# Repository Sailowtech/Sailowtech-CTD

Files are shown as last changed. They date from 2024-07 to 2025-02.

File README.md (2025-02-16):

# Sailowtech-CTD - Low-Tech CTD Probe
Welcome on the repository of the Sailowtech CTD Project, an affordable and open-source CTD probe tailored for scientific expeditions.

## Why does this project exist?
After all, Open Source CTD probes already exist? Indeed, there are some great projects like [Open CTD](https://github.com/OceanographyforEveryone/OpenCTD "Open CTD Project") or [CTDizzle](https://github.com/IanTBlack/CTDizzle/tree/main "CTDizzle Project"), but we wanted something more tailored for mid to long term expeditions while allowing a modularity in the embedded sensors. Therefore, we aim to develop a project around a main electronic core and auxiliary cards that can be swapped depending on the research interest. For the moment, we propose a core based on a Raspberry PI Zero 2 W and an auxiliary cards for 2 Atlas Scientific Sensors (Conductivity, Temperature, Dissolved Oxygen, pH...).

## Issues
If you encounter any issues, please use the Issue tracker on GitHub. Please note that this project is still in the development phase and currently undergoing testing.

## Full documentation
The full documentation is accessible under [https://sailowtech.github.io/Sailowtech-CTD/](https://sailowtech.github.io/Sailowtech-CTD/)

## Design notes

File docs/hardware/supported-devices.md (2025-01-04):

# Supported Devices

This page lists all supported sensor devices.

## Bluerobotics Bar30 - High-Resolution 300m Depth/Pressure Sensor

Default I2C-Address: 0x76

Sailowtech-ID: *BAR30_DEPTH*

Vendor Page: https://bluerobotics.com/store/sensors-cameras/sensors/bar30-sensor-r1/

Provides Metric: Pressure / Depth

## Atlas Scientific Conductivity Probe with EZO circuit

Default I2C-Address: 0x64

Sailowtech-ID: *ATLAS_EZO_CONDUCTIVITY*

Vendor Page:
- https://atlas-scientific.com/embedded-solutions/ezo-conductivity-circuit/
- https://atlas-scientific.com/probes/mini-e-c-probe-k-1-0/

Provides Metric: Conductivity

## Atlas Scientific Dissolved Oxygen with EZO circuit

Default I2C-Address: 0x61

Sailowtech-ID: *ATLAS_EZO_DO*

Vendor Page:
- https://atlas-scientific.com/embedded-solutions/ezo-dissolved-oxygen-circuit/
- https://atlas-scientific.com/probes/industrial-dissolved-oxygen-probe/

Provides Metric: Dissolved Oxygen

## Atlas Scientific Temperature Sensor
PT-1000 or PT-100, can be in Dissolved Oxygen Probe

Default I2C-Address: 0x66

Sailowtech-ID: *ATLAS_EZO_TEMP*

Vendor Page:
- https://atlas-scientific.com/embedded-solutions/ezo-rtd-temperature-circuit/
- https://atlas-scientific.com/probes/industrial-dissolved-oxygen-probe/

Provides Metric: Temperature

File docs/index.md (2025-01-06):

# Sailowtech-CTD

Welcome to the Documentation of the Sailowtech-CTD project!
This project is run by [Sailowtech](https://sailowtech.ch), an association at [EPFL](https://epfl.ch).

The repository of the project is located at [https://github.com/Sailowtech/Sailowtech-CTD](https://github.com/Sailowtech/Sailowtech-CTD). Please use the issue tracker over there if you want to report any issues.

## Setup Raspberry PI
To set up the Raspberry Pi on a CTD, the image needs to be flashed. Details are on this page: [Installation and Setup](operating-system/installing.md)

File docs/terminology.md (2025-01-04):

# Terminology

This page outlines the basic terminology used in this project.

## Metric

A **metric** is a type of measurement.
For example, *Temperature*, *Pressure* and other such things.

## Measurement

A **measurement** is a datapoint with the value of a *metric* which was measured at a specific time.

## Sensor

A **sensor** is a physical device which is installed on the CTD. It takes measurements of a metric. Note that even though some devices take measures of multiple metrics, we abstract it to one metric per device. 

## Correlation Data

**Correlation Data** can be used to add additional measurements to the recorded data. This is mostly the case to add location and speed data, since the CTD is not tracking the location.

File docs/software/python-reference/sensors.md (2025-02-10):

# Sensors
## Generic Sensor

::: sailowtech_ctd.sensors.generic

## Mock Sensor

::: sailowtech_ctd.sensors.mocksensor

## Atlas Sensor

::: sailowtech_ctd.sensors.atlas

## Bluerobotics Sensor

::: sailowtech_ctd.sensors.bluerobotics

## Types

::: sailowtech_ctd.sensors.types

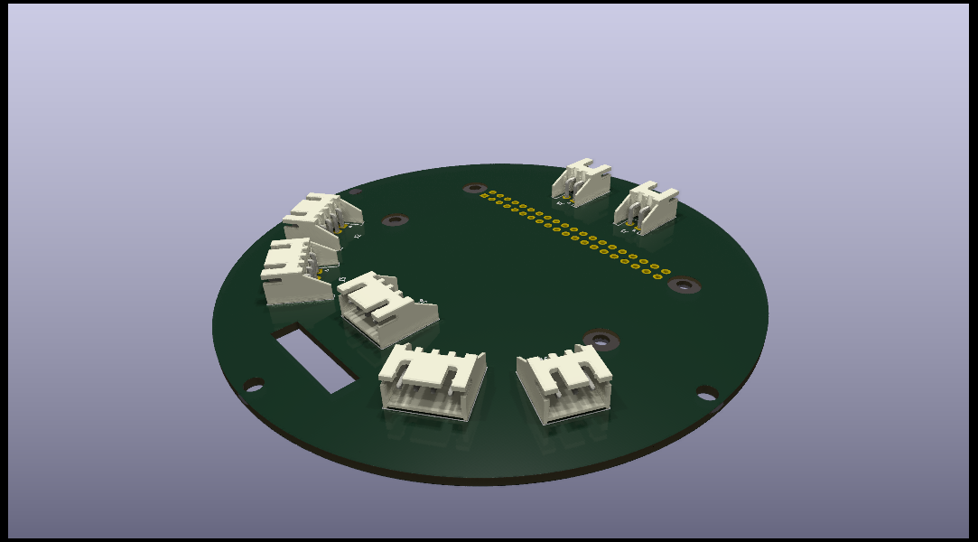
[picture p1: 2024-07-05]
hardware/ctd-base/ctd-base.png

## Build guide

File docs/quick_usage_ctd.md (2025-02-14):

# Quick usage guide

## Turn on the CTD
The CTD can be turned on by closing (turning clockwise) the on/off switch as marked in the image below.
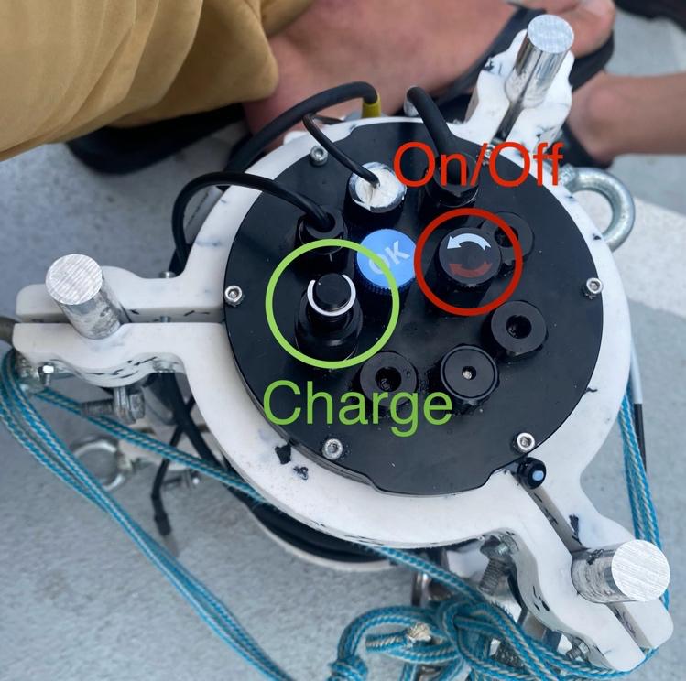
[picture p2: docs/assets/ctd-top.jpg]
CTD


## Connect to the CTD
The CTD will start after turning on the power supply. Please note that this might take up to one minute.
A Wi-Fi network called `CTD` will then appear. Connect to it with the password `CTDCTDCTD`.

!!! info "Development Build Access point"
    Please note that the Access Point name for the development build is called `CTDDEV`, but has the same password `CTDCTDCTD`

For further settings and system upgrades, it is possible to connect over SSH `ssh ctd@192.168.42.1` and password `ctd`.

## Record data using the web interface
If you are connected to the `CTD` Wi-Fi, the web interface is reachable over [http://192.168.42.1](http://192.168.42.1)

!!! warning "Web interface is currently being developed"
    The web interface is currently being developed. Some functionality is missing, and there are still some bugs.
    Mainly, there is no auto-reload, so please reload the web-page after starting a measurement and before stopping a measurement on the development web interface.

### Start a recording
To start a recording, click the button `Start Manual Run` on the webinterface. Only click it once. To make sure the recording has started, reload the page.

### Stop a recording
To stop the recording, click on the button `Stop Running` of the corresponding run in the webinterface.

### Download data
To download the data, locate the desired run in the list, and click on `Download data`

## Take a measurement with the CTD
!!! danger "Don't lose the CTD lol"
    Always make sure that the rope of the CTD is attached correctly, and the pressure closure (the round screw thingy on top with OK written on it) is fully screwed close.
    Note down the GPS coordinates, the depth and the water current direction in the unlikely case it gets lost.

To take a measure:

1. Attach the rope, check if the CTD is closed correctly, and remove the caps of the sensors
2. Make sure the boat is stopped and not moving too much
3. Note down the current GPS location and time
4. Connect to the CTD webinterface, start a manual run (as noted above), reload the webpage and write down the run-id - this is the number indicated at the beginning of the `Currently running` entry.
5. Put the CTD into the water, firmly attach the end of the rope to the boat
6. (When using for the first time, you might want to leave it in the water for ~3 minutes at 20cm depth, then take it out again, and check if no water got inside)
7. Lower the CTD into the water at a constant speed - for example 5cm/s -> 10 minutes to lower 30m
8. Leave the CTD at the lowest point for ~1 minute for the readings to stabilise
9. Pull the CTD up again. You can pull it up faster than the speed for lowering it. It also doesn't have to be constant.
10. Take the CTD out of the water
11. Connect to the Wi-Fi and webinterface again and stop the recording
12. Download the data of the run by clicking on the corresponding button

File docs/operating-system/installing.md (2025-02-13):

# Installation and Setup

It is assumed that a working CTD with a **Raspberry Pi Zero 2 W** is used for this setup.

## Download Image
The OS-images are automatically built for each release. Download the image (the file starting with *image*) of the latest release on the [Release Page](https://github.com/Sailowtech/Sailowtech-CTD/releases/).

Then, unpack the zip-file that was downloaded.

## Flash the image
The image needs to be flashed onto the SD-Card of the Raspberry Pi.
You can use one of those tools, for example:

- RPI-Imager: [https://www.raspberrypi.com/software/](https://www.raspberrypi.com/software/)
- Balena Etcher: [https://etcher.balena.io/](https://etcher.balena.io/)
- DD: [https://wiki.archlinux.org/title/Dd](https://wiki.archlinux.org/title/Dd)

Flash the downloaded *.img* file to the SD-Card by following the instructions of the tool you chose.

## Start the CTD, connect to the access point and log in
Plug in the SD-Card into the Raspberry Pi and start it. It will boot automatically and start an access point with the SSID `CTD`
Connect to this access point with password `CTDCTDCTD`. 

Then, connect over SSH with user `ctd` and password `ctd`:

`ssh ctd@192.168.42.1`

## Change passwords
Ideally, you should change the credentials of the `ctd`-user and also use another password for the access point.

The AP-password used can be changed in `/etc/hostapd/hostapd.conf`

## Setup internet access (if needed)
In case internet access is needed from the Raspberry Pi, you can set it up (with linux device as the other device, we'll call client).

1. Check which ip-address is assigned by the Raspberry Pi to the AP-client with `ifconfig` (for example: 192.168.42.4)
2. Enable IPv4-forwarding on client: `echo 1 | sudo tee /proc/sys/net/ipv4/ip_forward`
3. Set up iptables, replace `eth0` with name of interface with internet access and `wlan0` with name of interface connected to the Raspberry Pi:
   1. `sudo iptables -t nat -A POSTROUTING -o eth0 -j MASQUERADE`
   2. `sudo iptables -A FORWARD -i wlan0 -o eth0 -j ACCEPT`
4. Then, on the Raspberry Pi, add the route: `sudo ip route add default via 192.168.42.4` (adapt IP-address if required)
5. Add nameserver: `echo "nameserver 9.9.9.9" | sudo tee /etc/resolv.conf`

## Running the software

1. Connect to the Raspberry Pi
2. Change to the correct directory: `cd Sailowtech-CTD`
3. Start the webserver: `poetry run web`

It will then be reachable over: http://192.168.42.1:8000

Start measurements over http://192.168.42.1:8000/run?measurements=100 where the last number is the amount of measurements

Then http://192.168.42.1:8000/csv to get all the data

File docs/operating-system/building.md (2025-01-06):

# Self-Building Image

The image is built automatically on GitHub.

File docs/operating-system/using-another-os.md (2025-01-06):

# Use another Operating System

Of course, it is possible to use another Operating System instead of the one from the Sailowtech-CTD.

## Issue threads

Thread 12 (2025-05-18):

Time synchronisation not working correctly

maurosbicego, 2025-05-18:
The time synchronization in the web interface is not working correctly on the current development CTD device, even though tests were successful on a Raspberry Pi of the same model. Check if the cause lies in the general implementation or in the installation on the development CTD.

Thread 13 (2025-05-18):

Rework CSV export options

maurosbicego, 2025-05-18:
CSV export should / can now be possible with the different sensors distributed horizontally. One CSV entry per timestamp with the different values of the sensors. Now we have one CSV entry per sensor and timestamp.
Check implementation when downloading files in the web interface.

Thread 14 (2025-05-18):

Graph visualization is not working properly with an adapted config (Temperature data not available)

maurosbicego, 2025-05-18:
After adapting the config to a new set of sensors, the visualization in the web interface was not working properly. Data for temperature was not visible in our tests.

Example of missing temperature data:
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

(The data was measured correctly and is stored in the DB)

Used Config:

```
device: Sailowtech CTD
sensors:
  dissolved-oxygen:
    name: "Dissolved Oxygen 1"
    address: 0x61
    sensor-type: "ATLAS_EZO_DO"
    min-delay: 1.05
  dissolved-oxygen-2:
    name: "Dissolved Oxygen 2"
    address: 0x62
    sensor-type: "ATLAS_EZO_DO"
    min-delay: 1.05
  conductivity:
    name: "Conductivity Probe"
    address: 0x64
    sensor-type: "ATLAS_EZO_CONDUCTIVITY"
    min-delay: 1.05
  temperature-do:
    name: "Temperature (DO Sensor)"
    address: 0x67
    sensor-type: "ATLAS_EZO_TEMP"
    min-delay: 1.05
  depth:
    name: "Depth Sensor"
    address: 0x76
    sensor-type: "BLUEROBOTICS_BAR30_DEPTH"
    min-delay: 1.05
mock: false
```

Reporter: @benedictelunven

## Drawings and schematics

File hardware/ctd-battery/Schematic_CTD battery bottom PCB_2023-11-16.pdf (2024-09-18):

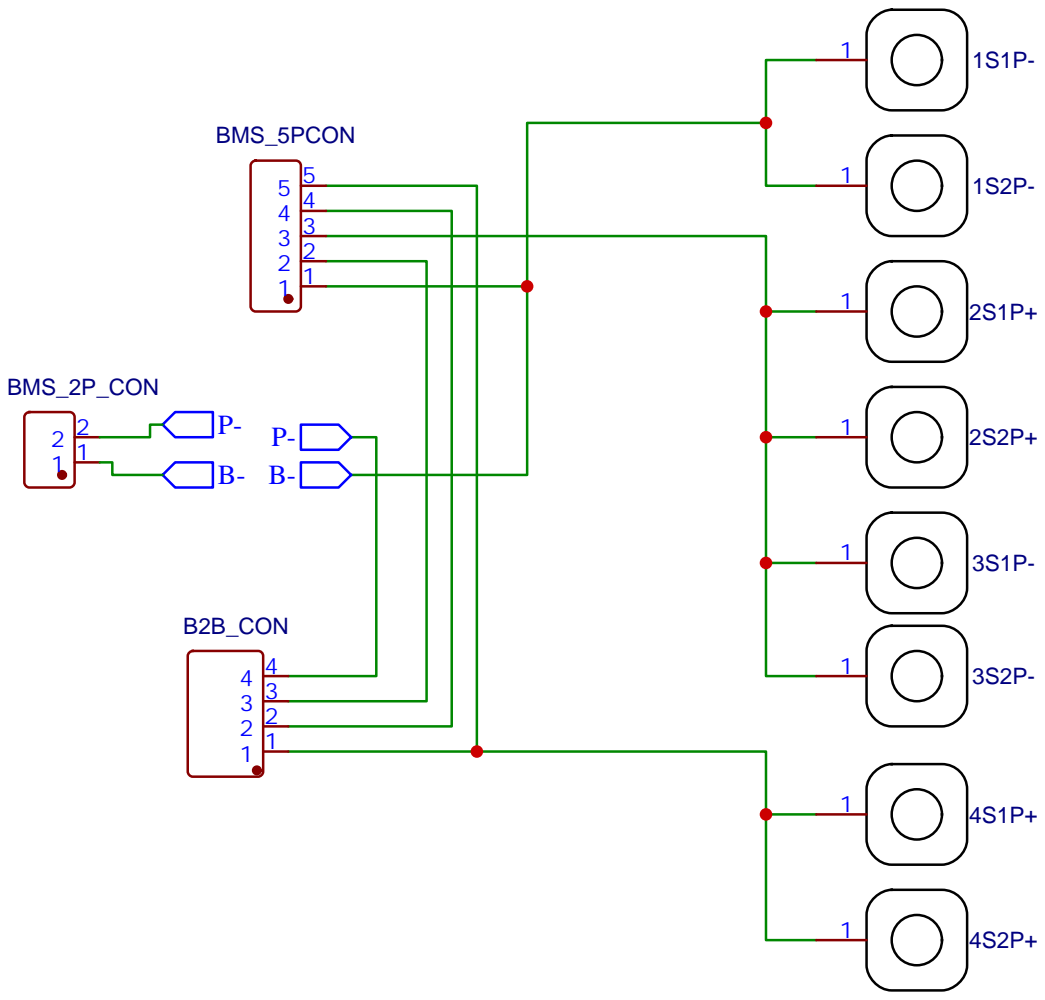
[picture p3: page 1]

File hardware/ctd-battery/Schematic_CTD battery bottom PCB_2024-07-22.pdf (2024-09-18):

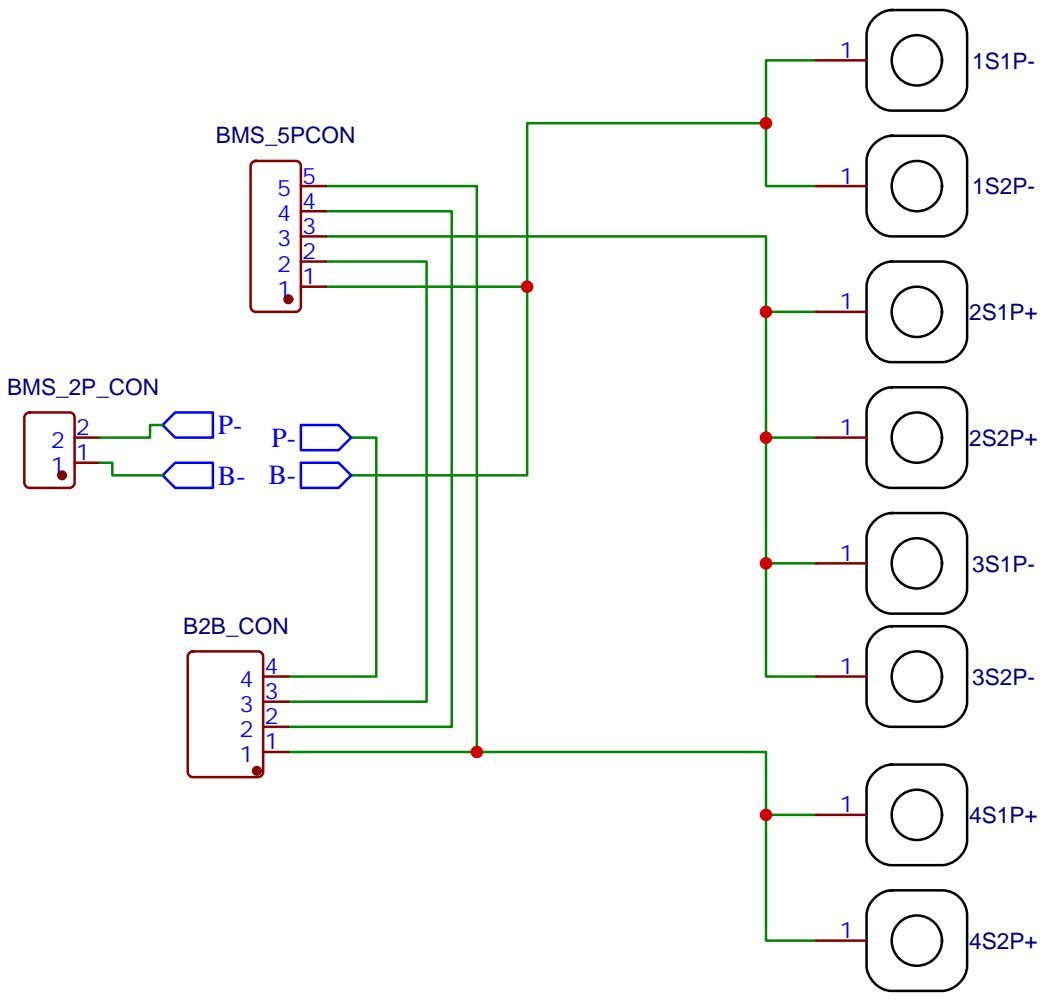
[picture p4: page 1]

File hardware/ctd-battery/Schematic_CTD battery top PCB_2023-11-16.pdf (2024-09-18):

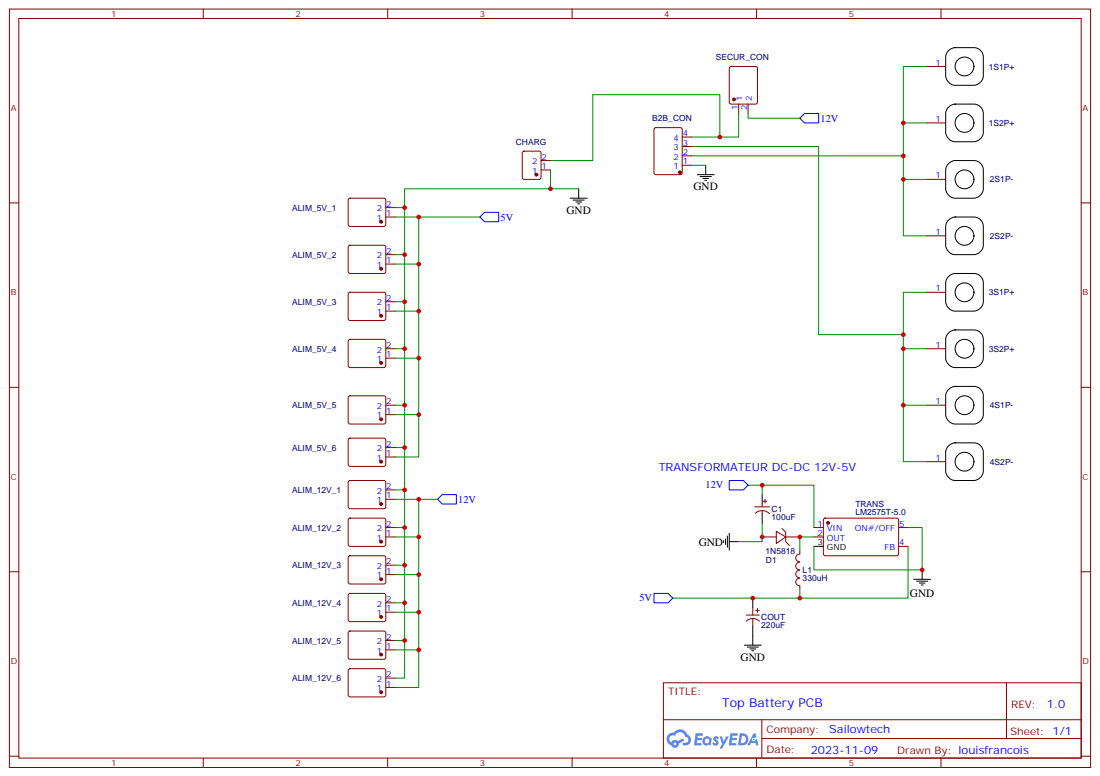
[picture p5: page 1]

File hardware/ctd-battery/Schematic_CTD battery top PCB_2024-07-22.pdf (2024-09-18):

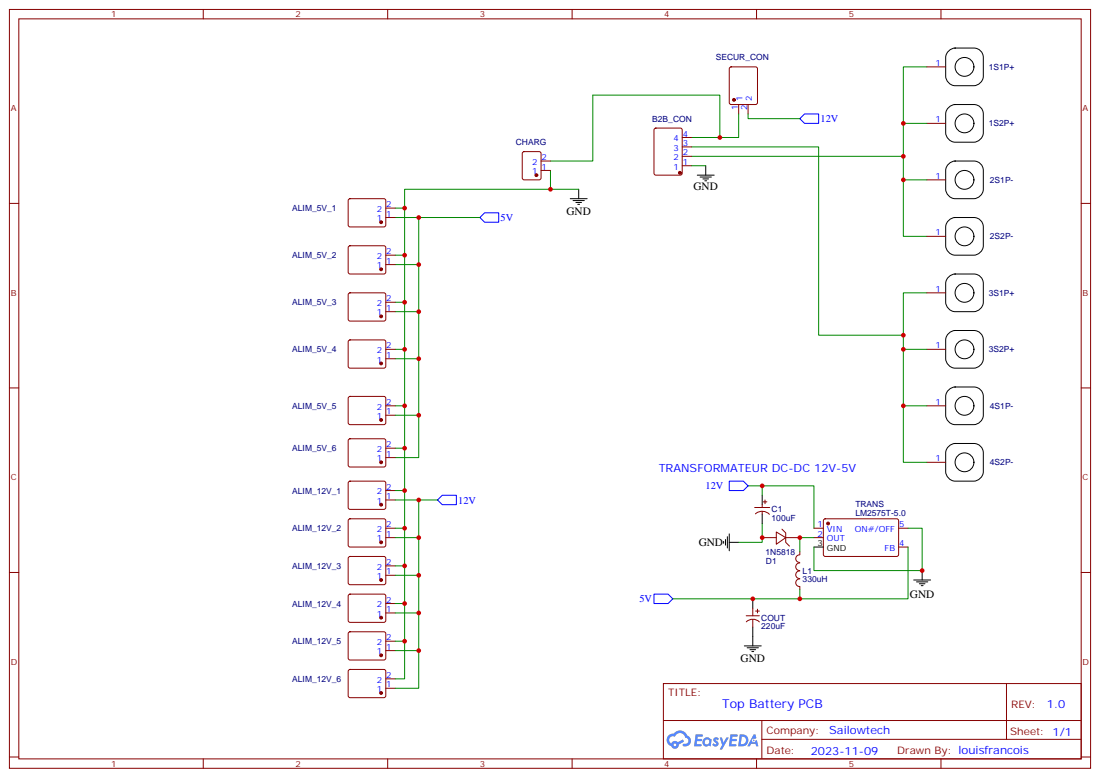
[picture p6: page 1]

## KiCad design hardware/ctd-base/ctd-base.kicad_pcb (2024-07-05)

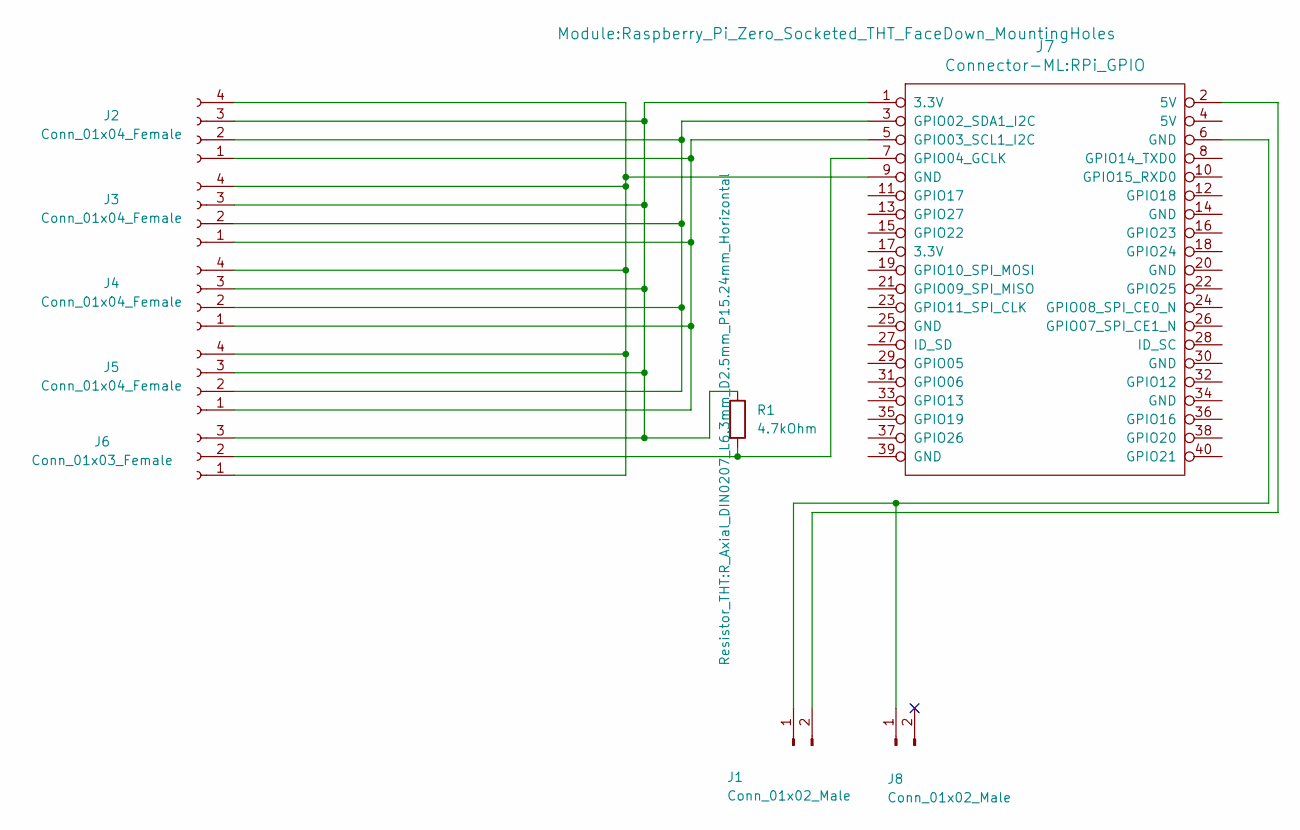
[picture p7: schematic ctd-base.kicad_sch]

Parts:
J1, J8: Conn_01x02_Male; JST_XH_S2B-XH-A_1x02_P2.50mm_Horizontal
J2, J3, J4, J5: Conn_01x04_Female; JST_XH_S4B-XH-A-1_1x04_P2.50mm_Horizontal
J6: Conn_01x03_Female; JST_XH_S3B-XH-A_1x03_P2.50mm_Horizontal
J7: Connector-ML:RPi_GPIO; Raspberry_Pi_Zero_Socketed_THT_FaceDown_MountingHoles
R1: 4.7kOhm; R_Axial_DIN0207_L6.3mm_D2.5mm_P15.24mm_Horizontal

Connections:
unnamed: J1.1, J7.6 (GND), J8.1
unnamed: J1.2, J7.2 (5V)
unnamed: J2.1, J3.1, J4.1, J5.1, J7.5 (GPIO03_SCL1_I2C)
unnamed: J2.2, J3.2, J4.2, J5.2, J7.3 (GPIO02_SDA1_I2C)
unnamed: J2.3, J3.3, J4.3, J5.3, J6.3, J7.1 (3.3V), R1.1
unnamed: J2.4, J3.4, J4.4, J5.4, J6.1, J7.9 (GND)
unnamed: J6.2, J7.7 (GPIO04_GCLK), R1.2

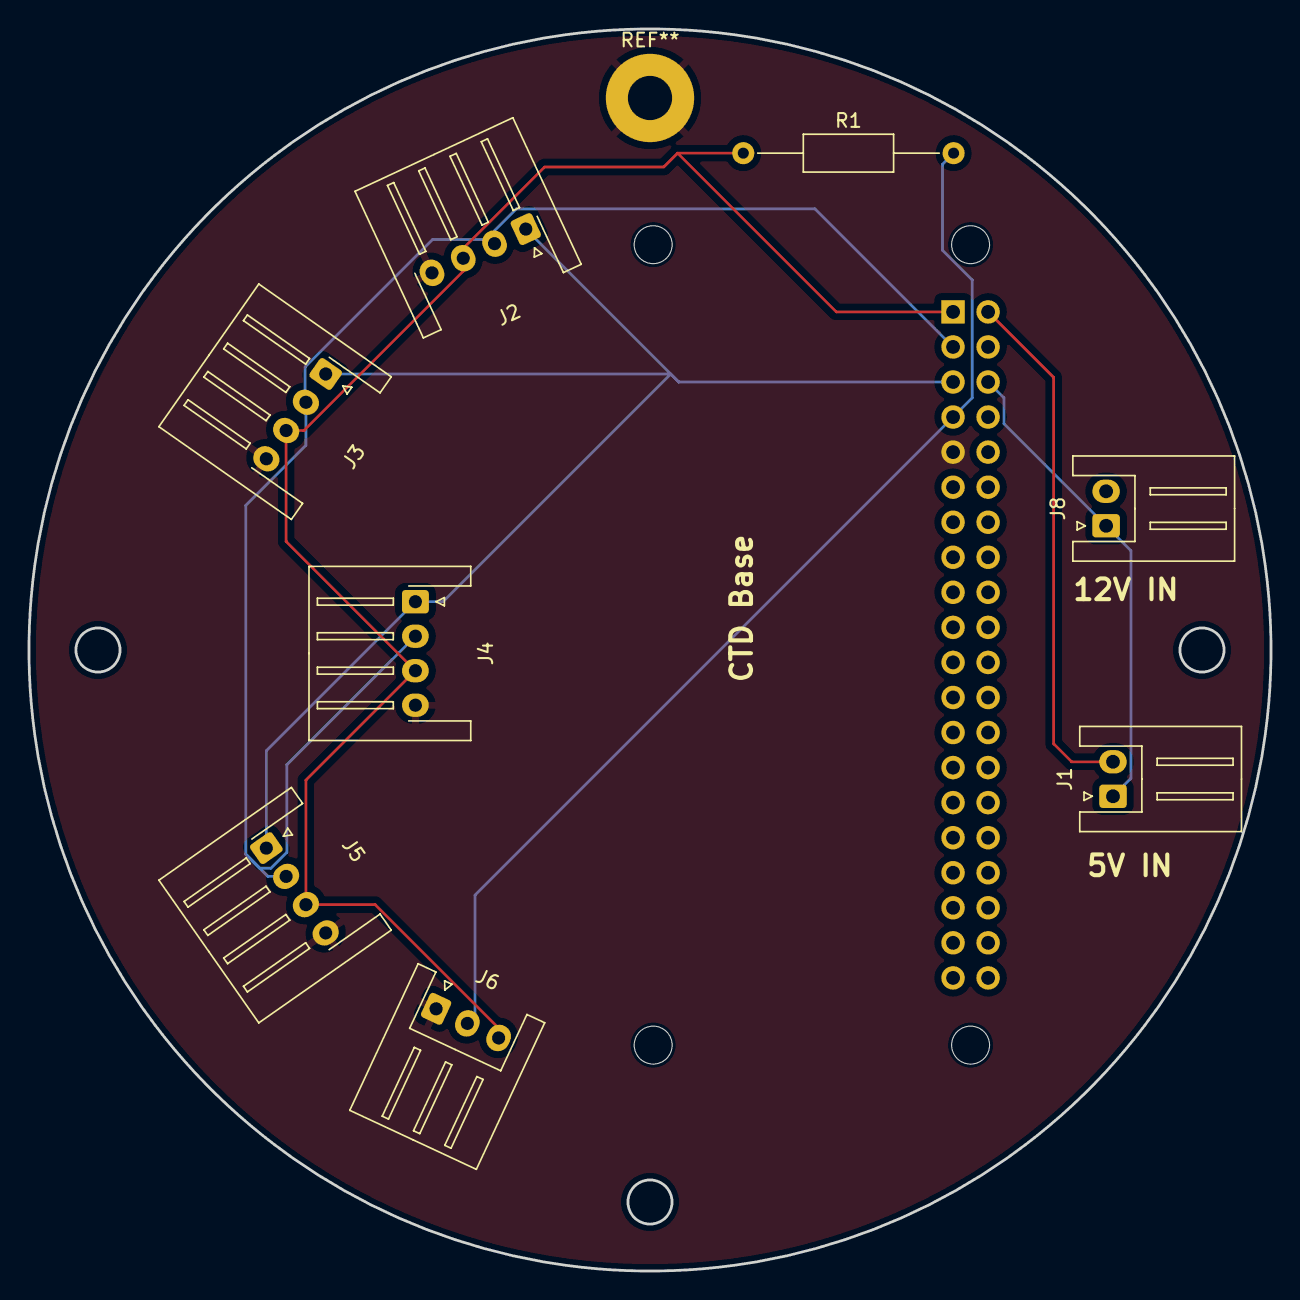
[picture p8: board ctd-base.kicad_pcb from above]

Board: 2 copper layers, 90.0 x 90.0 mm, 9 parts (1 on the bottom side), 7 nets.

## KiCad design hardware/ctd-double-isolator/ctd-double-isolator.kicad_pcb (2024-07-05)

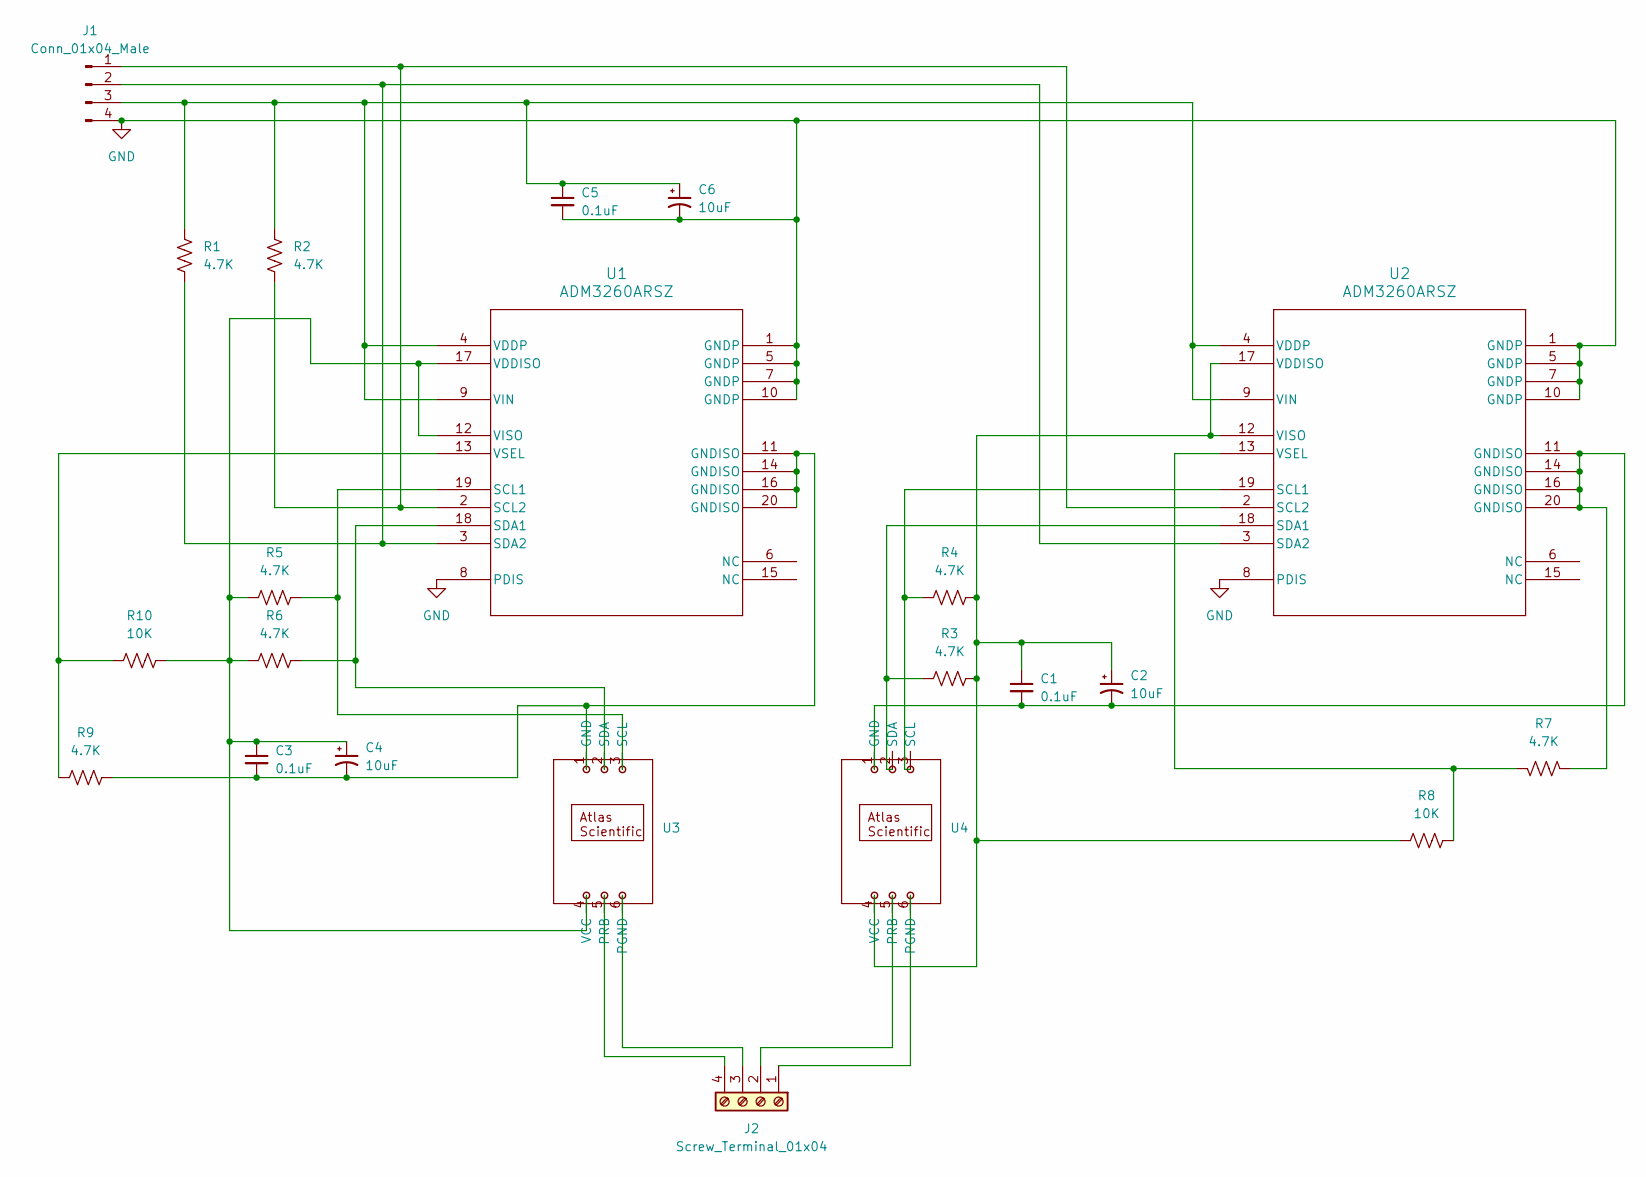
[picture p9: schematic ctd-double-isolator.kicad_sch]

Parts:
C1, C3, C5: 0.1uF; C_1812_4532Metric_Pad1.57x3.40mm_HandSolder
C2, C4, C6: 10uF; C_1812_4532Metric_Pad1.57x3.40mm_HandSolder
J1: Conn_01x04_Male; JST_XH_S4B-XH-A-1_1x04_P2.50mm_Horizontal
J2: Screw_Terminal_01x04; TerminalBlock_Phoenix_MPT-0,5-4-2.54_1x04_P2.54mm_Horizontal
R1, R2, R3, R4, R5, R6, R7, R9: 4.7K; R_Axial_DIN0207_L6.3mm_D2.5mm_P10.16mm_Horizontal
R8, R10: 10K; R_Axial_DIN0207_L6.3mm_D2.5mm_P10.16mm_Horizontal
U1, U2: ADM3260ARSZ; RS_20_ADI
U3: Atlas Scientific Dissolved Oxygen
U4: Atlas Scientific RTD Temperature Circuit

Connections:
GND: C5.2, C6.2, J1.4, U1.1 (GNDP), U1.5 (GNDP), U1.7 (GNDP), U1.8 (PDIS), U1.10 (GNDP), U2.1 (GNDP), U2.5 (GNDP), U2.7 (GNDP), U2.8 (PDIS), U2.10 (GNDP)
unnamed: J1.1, R2.2, U1.2 (SCL2), U2.2 (SCL2)
unnamed: J1.2, R1.2, U1.3 (SDA2), U2.3 (SDA2)
unnamed: C5.1, C6.1, J1.3, R1.1, R2.1, U1.4 (VDDP), U1.9 (VIN), U2.4 (VDDP), U2.9 (VIN)
unnamed: J2.1, U4.6 (PGND)
unnamed: J2.2, U4.5 (PRB)
unnamed: J2.3, U3.6 (PGND)
unnamed: J2.4, U3.5 (PRB)
unnamed: R5.2, U1.19 (SCL1), U3.3 (SCL)
unnamed: R6.2, U1.18 (SDA1), U3.2 (SDA)
unnamed: C3.1, C4.1, R5.1, R6.1, R10.2, U1.12 (VISO), U1.17 (VDDISO), U3.4 (VCC)
unnamed: R9.1, R10.1, U1.13 (VSEL)
unnamed: R4.1, U2.19 (SCL1), U4.3 (SCL)
unnamed: R3.1, U2.18 (SDA1), U4.2 (SDA)
unnamed: C1.1, C2.1, R3.2, R4.2, R8.1, U2.12 (VISO), U2.17 (VDDISO), U4.4 (VCC)
unnamed: R7.2, R8.2, U2.13 (VSEL)
unnamed: C3.2, C4.2, R9.2, U1.11 (GNDISO), U1.14 (GNDISO), U1.16 (GNDISO), U1.20 (GNDISO), U3.1 (GND)
unnamed: C1.2, C2.2, R7.1, U2.11 (GNDISO), U2.14 (GNDISO), U2.16 (GNDISO), U2.20 (GNDISO), U4.1 (GND)

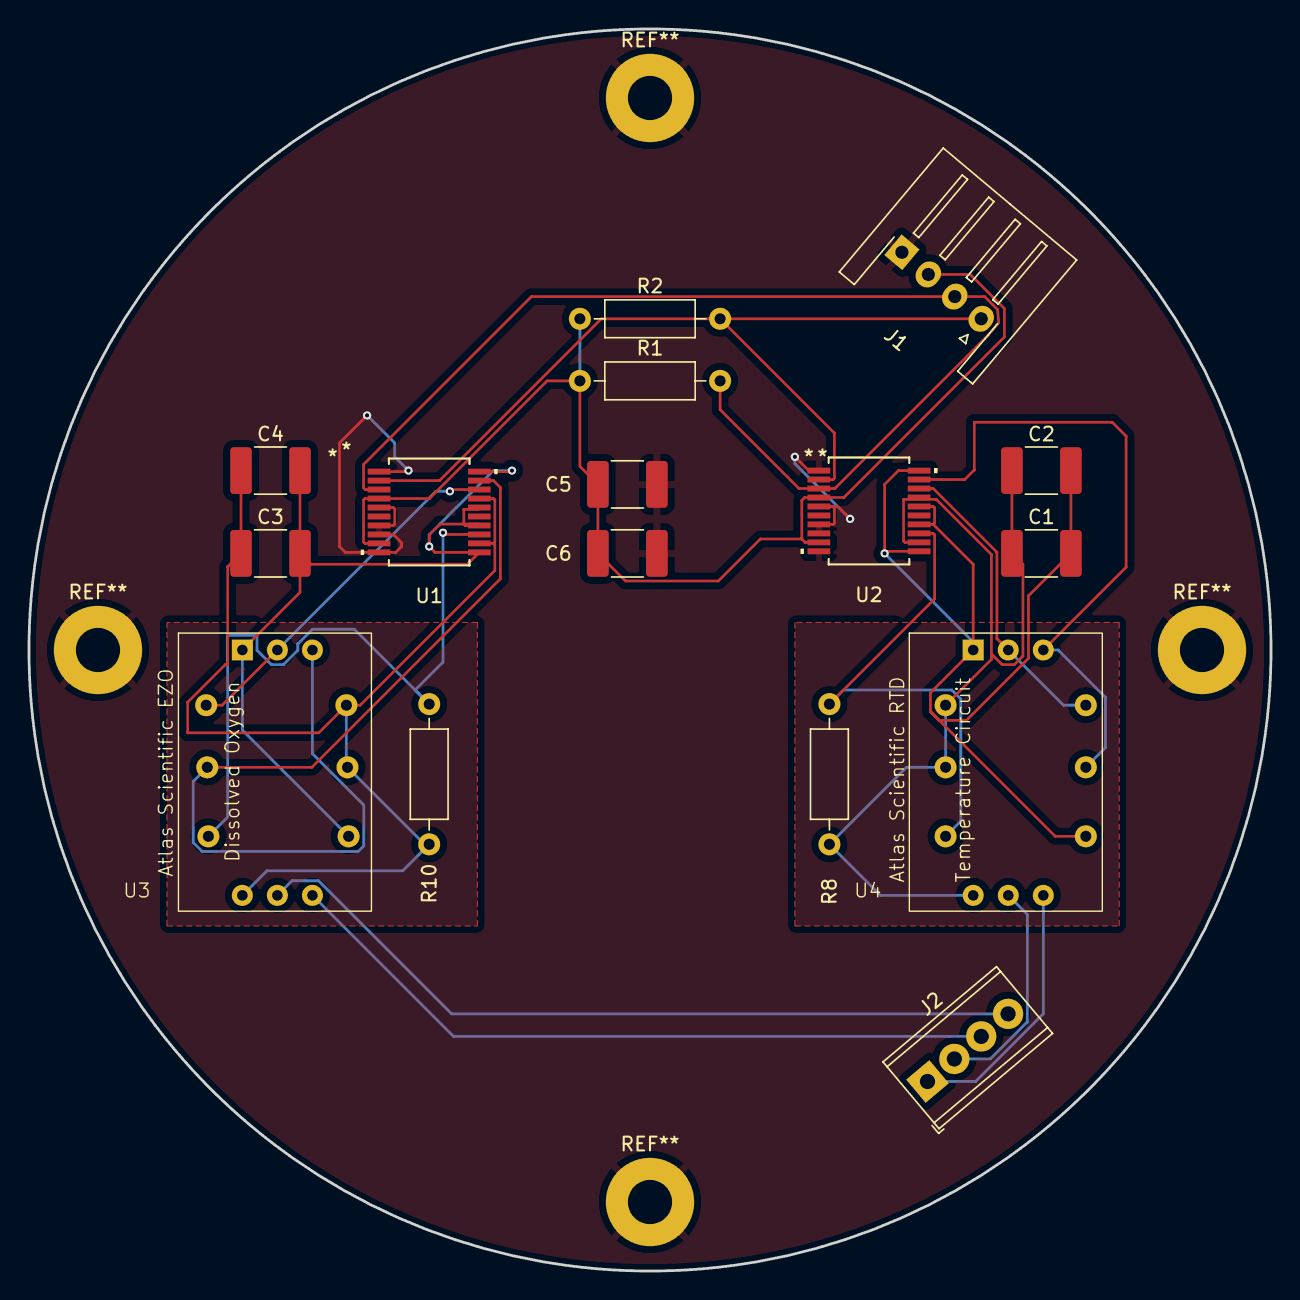
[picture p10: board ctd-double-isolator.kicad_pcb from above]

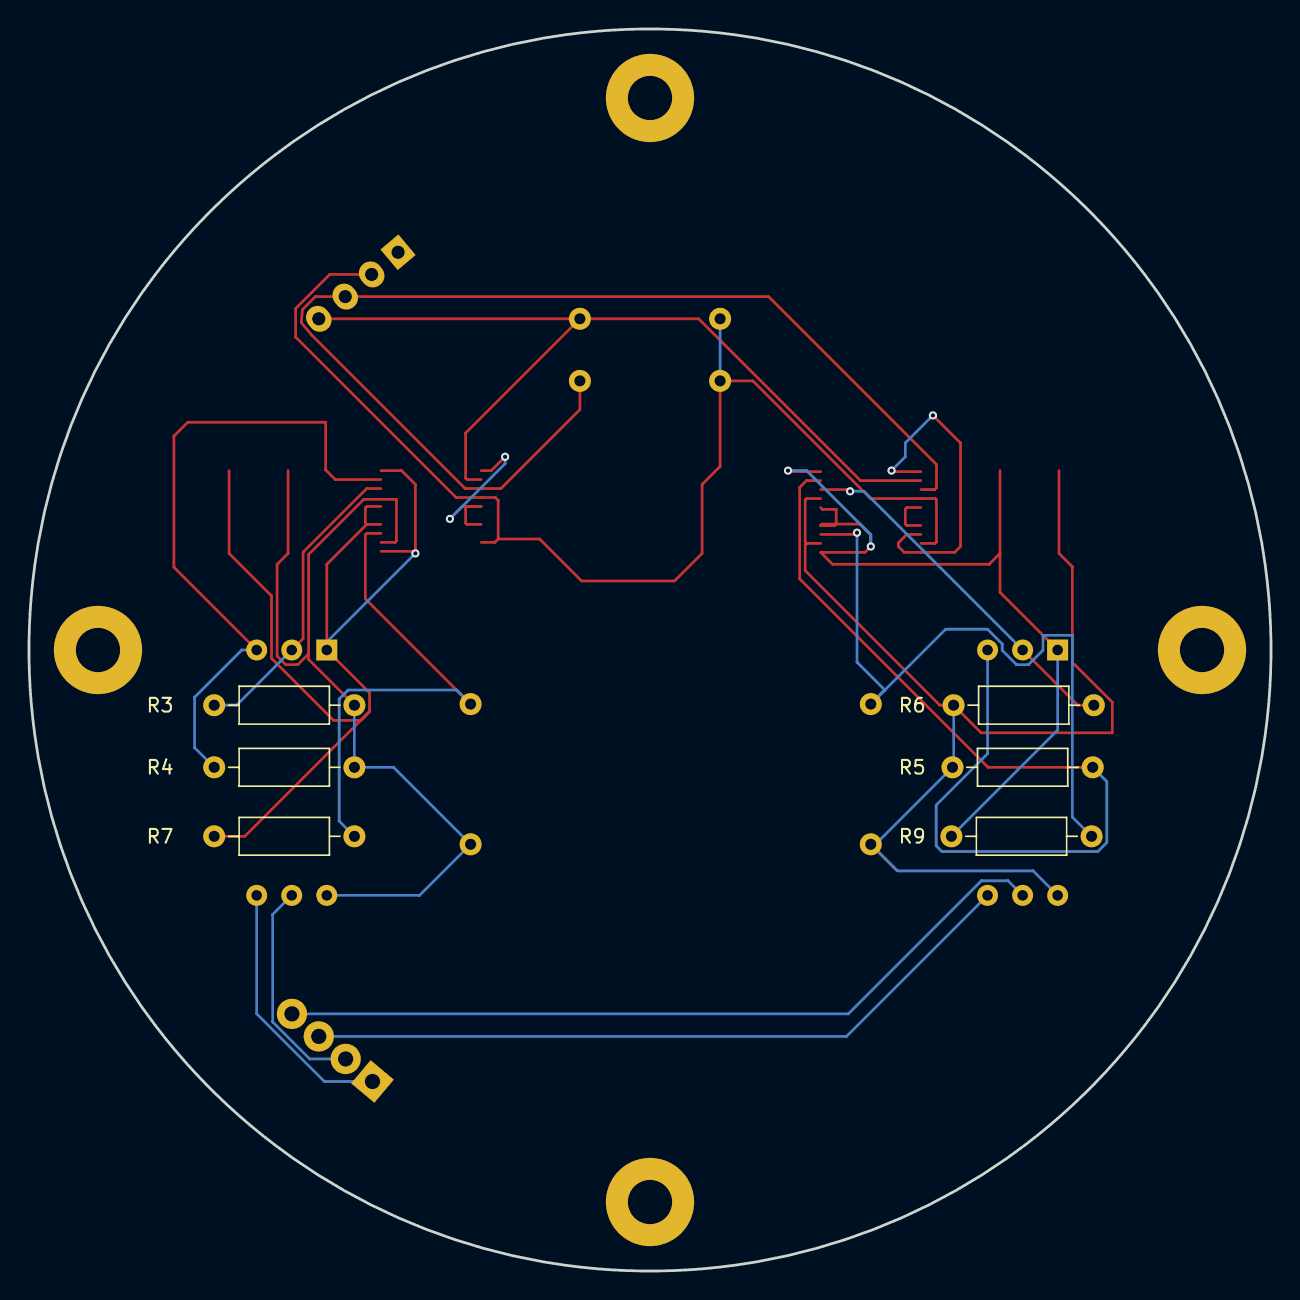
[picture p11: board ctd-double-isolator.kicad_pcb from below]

Board: 2 copper layers, 90.0 x 90.0 mm, 22 parts (6 on the bottom side), 18 nets.

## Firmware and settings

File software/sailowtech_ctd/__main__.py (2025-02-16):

#!/usr/bin/env python
# -*- coding: utf-8 -*-

"""
This program aims to facilitate communication with multiple sensors inside a CTD.
For now, it supports I2C protocol but there should be more in the future.

Credits for I2C protocol: "https://github.com/Atlas-Scientific/Raspberry-Pi-sample-code/blob/master/AtlasI2C.py"
Contact                 : "arthur.jacobs@sailowtech.ch"
"""

from datetime import datetime
import time

import uvicorn
import threading

from software.sailowtech_ctd.database.measurement import Measurement
from software.sailowtech_ctd.database.metric import Metric, assert_metrics_setup
from software.sailowtech_ctd.database.sensor import Sensor
from software.sailowtech_ctd.logger import logger
from software.sailowtech_ctd.database import db
from software.sailowtech_ctd.ctd import CTD
from software.sailowtech_ctd.database.run import Run, RunTypes

from software.sailowtech_ctd.methods.config_parser import load_file_to_yaml, get_sensors, is_mock


def start():
    """Start app with uvicorn"""
    web_thread = threading.Thread(target=uvicorn.run, kwargs={"app": "software.sailowtech_ctd.webapi.app:app", "host": "0.0.0.0", "port": 80})
    logger.info("Starting web service thread...")
    web_thread.start()
    logger.info("Started web service thread")
    main_loop("software/sailowtech_ctd/config.yaml")


def start_debug():
    """Start app with uvicorn"""
    web_thread = threading.Thread(target=uvicorn.run, kwargs={"app": "software.sailowtech_ctd.webapi.app:app", "host": "0.0.0.0", "port": 8000})
    logger.info("Starting web service thread...")
    web_thread.start()
    logger.info("Started web service thread")
    main_loop("software/sailowtech_ctd/config-mock.yaml")


def init_db():
    db.connect()
    db.create_tables([Measurement, Run, Sensor, Metric])
    assert_metrics_setup()

def main_loop(configfile: str):
    logger.info("Main Loop is starting")
    sel = Run.select().where(Run.running == True)
    if len(sel) > 0:
        logger.info("Stopping all currently running Runs")
        for r in sel:
            r.running = False
            r.save()

    config = load_file_to_yaml(configfile)
    mockery = is_mock(config)

    ctd = CTD()
    ctd.set_sensors(get_sensors(config))
    ctd.setup_sensors()

    while True:
        logger.info("Checking for active runs")
        sel = Run.select().where(Run.running == True)
        if len(sel) > 1: logger.warning("More than one run is started!")
        if len(sel) > 0:
            logger.info(f"Found {len(sel)} active runs")
            for r in sel[:]:
                match r.run_type:
                    case RunTypes.MANUAL_STOP:
                        pass
                    case RunTypes.TIME_DURATION:
                        if (datetime.now() - r.timestamp).total_seconds() >= r.wanted_duration:
                            r.running = False
                            r.save()
                            logger.info(f"Stopped run with id {r.id} since time run out")
                    case RunTypes.MEASUREMENT_COUNT:
                        if r.measurements.count() >= r.wanted_measurements:
                            r.running = False
                            r.save()
                        logger.info(f"Stopped run with id {r.id} since measurement limit was reached")
                logger.info(f"Checking if measuring is necessary for run {r.id}")
                if ctd.is_bus_connected | mockery:
                    logger.info(f"Measuring for run {r.id}")
                    ctd.measure_all(r.id)
                else:
                    logger.error("CTD Bus is not connected")
        else:
            time.sleep(1) # Info: we are only sleeping when nothing is running to improve efficiency


if __name__ == '__main__':
    start_debug()

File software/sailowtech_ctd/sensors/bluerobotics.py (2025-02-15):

from time import sleep
import smbus2 as smbus

from software.sailowtech_ctd.sensors.generic import GenericSensor, SensorBrand
from .types import Sensor, Metric


class BlueRoboticsSensor(GenericSensor):
    """
    Base for a Bluerobotics sensor
    """
    def __init__(self, sensor: Sensor, name: str, address: int, min_delay: float):
        super().__init__(SensorBrand.BlueRobotics, sensor, name, address, min_delay, Metric.DEPTH)


class DepthSensor(BlueRoboticsSensor):
    """
    Class for a depth sensor by Bluerobotics
    """
    _MS5837_ADDR = 0x76
    _MS5837_RESET = 0x1E
    _MS5837_ADC_READ = 0x00
    _MS5837_PROM_READ = 0xA0
    _MS5837_CONVERT_D1_256 = 0x40
    _MS5837_CONVERT_D2_256 = 0x50

    DEFAULT_ADDRESS = 98

    # Models
    MODEL_02BA = 0
    MODEL_30BA = 1

    # Oversampling options
    OSR_256 = 0
    OSR_512 = 1
    OSR_1024 = 2
    OSR_2048 = 3
    OSR_4096 = 4
    OSR_8192 = 5

    # kg/m^3 convenience
    DENSITY_FRESHWATER = 997
    DENSITY_SALTWATER = 1029

    # Conversion factors (from native unit, mbar)
    UNITS_Pa = 100.0
    UNITS_hPa = 1.0
    UNITS_kPa = 0.1
    UNITS_mbar = 1.0
    UNITS_bar = 0.001
    UNITS_atm = 0.000986923
    UNITS_Torr = 0.750062
    UNITS_psi = 0.014503773773022

    # Valid units
    UNITS_Centigrade = 1
    UNITS_Fahrenheit = 2
    UNITS_Kelvin = 3

    def __init__(self, name: str, address: int = DEFAULT_ADDRESS, min_delay: float = 1):
        """
        Initialise the class of the depth sensor
        :param name: Name of the sensor
        :param address: I2C-Address of the sensor
        :param min_delay: Required minimum delay
        """
        super().__init__(Sensor.BLUEROBOTICS_BAR30_DEPTH, name, address, min_delay)
        self._model = self.MODEL_30BA
        self._C = []

        self._fluidDensity = self.DENSITY_FRESHWATER
        self._pressure = 0
        self._temperature = 0
        self._D1 = 0
        self._D2 = 0

    def init(self, bus: smbus.SMBus) -> bool:
        """
        Initialise the device of the depth sensor
        :param bus: SMBus over which the device can be reached
        :return: True if successful
        """
        bus.write_byte(i2c_addr=self._MS5837_ADDR, value=self._MS5837_RESET)

        # Wait for reset to complete
        sleep(0.01)

        self._C = []

        # Read calibration values and CRC
        for i in range(7):
            c = bus.read_word_data(self._MS5837_ADDR, self._MS5837_PROM_READ + 2 * i)
            c = ((c & 0xFF) << 8) | (c >> 8)  # SMBus is little-endian for word transfers, we need to swap MSB and LSB
            self._C.append(c)

        crc = (self._C[0] & 0xF000) >> 12
        if crc != self._crc4(self._C):
            print("PROM read error, CRC failed!")
            return False
        return True

    def write_read_command(self, bus: smbus.SMBus) -> bool:
        return True

    def read_result(self, bus: smbus.SMBus) -> float:
        return self.measure_value(bus)

    def measure_value(self, bus: smbus.SMBus) -> float:
        """
        Measures the different values
        :param bus: SMBus over which the device can be reached
        :return: Returns the different values
        """
        self.read(bus)
        # TODO here, we are returning all the different values that we get from this sensor. However, we are only expecting one. We need to find a good solution on how to differentiate these readings across the objects. Maybe save both depth and pressure, since both can be useful and directly saving the depth can be good for easier quick-assessment
        return self.depth()

    ###############################################################
    # FULLY COPIED FROM BLUEROBOTICS's CODE, just some parameters adapted and "self."  added
    def read(self, bus: smbus.SMBus, oversampling=OSR_8192) -> bool:
        """
        Take a reading of the sensor
        :param bus: SMBus over which the device can be reached
        :param oversampling: Oversampling attribute
        :return: True if successful
        """
        if oversampling < self.OSR_256 or oversampling > self.OSR_8192:
            print("Invalid oversampling option!")
            return False

        # Request D1 conversion (pressure)
        bus.write_byte(self._MS5837_ADDR, self._MS5837_CONVERT_D1_256 + 2 * oversampling)

        # Maximum conversion time increases linearly with oversampling
        # max time (seconds) ~= 2.2e-6(x) where x = OSR = (2^8, 2^9, ..., 2^13)
        # We use 2.5e-6 for some overhead
        sleep(2.5e-6 * 2 ** (8 + oversampling))

        d = bus.read_i2c_block_data(self._MS5837_ADDR, self._MS5837_ADC_READ, 3)
        self._D1 = d[0] << 16 | d[1] << 8 | d[2]

        # Request D2 conversion (temperature)
        bus.write_byte(self._MS5837_ADDR, self._MS5837_CONVERT_D2_256 + 2 * oversampling)

        # As above
        sleep(2.5e-6 * 2 ** (8 + oversampling))

        d = bus.read_i2c_block_data(self._MS5837_ADDR, self._MS5837_ADC_READ, 3)
        self._D2 = d[0] << 16 | d[1] << 8 | d[2]

        # Calculate compensated pressure and temperature
        # using raw ADC values and internal calibration
        self._calculate()

        return True

    def set_fluid_density(self, density):
        """
        Set the fluid density of the water
        :param density: Density to be set
        :return: None
        """
        self._fluidDensity = density

    def pressure(self, conversion=UNITS_mbar) -> float:
        """
        Get the pressure in the requested unit. Defaults to mBar.
        :param conversion: The unit conversion which should be used to return the value
        :return: Returns the pressure measured
        """
        return self._pressure * conversion


    def temperature(self, conversion=UNITS_Centigrade) -> float:
        """
        Temperature in requested units. Default in degrees Celsius
        :param conversion: The conversion to be applied
        :return: Returns the temperature in requested unit
        """
        deg_c = self._temperature / 100.0
        if conversion == self.UNITS_Fahrenheit:
            return (9.0 / 5.0) * deg_c + 32
        elif conversion == self.UNITS_Kelvin:
            return deg_c + 273
        return deg_c


    def depth(self) -> float:
        """
        Depth relative to MSL pressure in given fluid density
        :return: Returns depth
        """
        return (self.pressure(self.UNITS_Pa) - 101300) / (self._fluidDensity * 9.80665)


    def altitude(self) -> float:
        """
        Altitude relative to MSL pressure
        :return: Altitude relative to MSL pressure
        """
        return (1 - pow((self.pressure() / 1013.25), .190284)) * 145366.45 * .3048

        # Cribbed from datasheet

    def _calculate(self) -> None:
        OFFi = 0
        SENSi = 0
        Ti = 0
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

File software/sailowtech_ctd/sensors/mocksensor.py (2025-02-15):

import smbus2 as smbus
import random

from software.sailowtech_ctd.sensors.generic import GenericSensor, SensorBrand
from software.sailowtech_ctd.sensors.types import Sensor, Metric


class MockSensor(GenericSensor):
    """
    Class which provides a mock sensor in order to be able to test the interface
    """
    def __init__(self, brand: SensorBrand, sensor_type: Sensor, name: str, address: int, min_val: int, max_val: int, min_delay: float, metric_type: Metric):
        """
        Initialise the mock sensor
        :param brand: Brand of the sensor (mock_sensor)
        :param sensor_type: Type of the sensor (mock_sensor)
        :param name: The given name for this sensor
        :param address: The address assigned to this sensor (is ignored)
        :param min_val: The minimum value that the mock sensor is returning
        :param max_val: The maximum value that the mock sensor is returning
        """
        self.min = min_val
        self.max = max_val
        self.min_delay = min_delay
        super().__init__(brand, sensor_type, name, address, self.min_delay, metric_type)

    def init(self, bus: smbus.SMBus):
        """
        Initialises the mock sensor. Always returns true since no setup is required
        :param bus: The bus to be used - is ignored
        :return: Returns True
        """
        return True

    def write_read_command(self, bus: smbus.SMBus) -> bool:
        """
        Method to write the read command to the sensor - is ignored
        :param bus: The bus to be used - is ignored
        :return: Returns True
        """
        return True

    def read_result(self, bus: smbus.SMBus) -> float:
        """
        Method to read the measurement result
        :param bus: The bus to be used - is ignored
        :return: Returns the measured value
        """
        return self.measure_value(bus)

    def measure_value(self, bus: smbus.SMBus):
        """
        Measure the value of the mock sensor. Returns a random value between the minimum and maximum set during class instantiation
        :param bus: The bus to be used - is ignored
        :return: Returns the randomly generated simulated measurement
        """
        return random.uniform(self.min, self.max)

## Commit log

2024-07-03 Initial test with all the sensors except one-wire
2024-07-05 Added SQLite Implementation for measurements and added PCB Designs
    [ctd-base.kicad_pcb, ctd-base.kicad_sch, ctd-double-isolator.kicad_pcb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]
2024-07-22 Regroup all sensors
2024-07-22 Create base sensors structure
2024-07-22 Add enums for sensors and their brands + hardcode all the sensors
2024-07-22 Use a dataclass hardcode all the sensors, much cleaner
2024-07-24 Use default sensors + add some properties (getters and setters)
2024-08-01 Use generic sensors instead of dataclass
2024-08-01 Add a commands Enum template in generic sensor
2024-08-02 Much implementations of Bluerobotics sensor
2024-08-02 Add init files and fix paths
    [__main__.py, atlas.py, bluerobotics.py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]
2024-08-02 Well that didn't work out
    [__main__.py, atlas.py, bluerobotics.py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]
2024-08-02 Ugly fix, should work
    [atlas.py, bluerobotics.py]
2024-08-02 Cleanup + finally fix libs imports (use poetry in ctd)
    [__main__.py, atlas.py, bluerobotics.py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]
2024-08-03 Print all values collected by the pressure sensor
2024-08-03 Add calibrate method template
2024-08-05 Use a user-defined pressure threshold to determine the end of the measurements (ctd goes up)
2024-08-05 Create unique date-based data files to prevent overwriting them with next measurement
    [__main__.py]
2024-08-08 First test of using both Atlas and BlueRobotics sensors
2024-08-08 Forgot to add sensors
2024-08-09 Move Depth Sensor up in the list
2024-10-04 Move schematics in proper folder
2025-01-02 Refactoring of types
    The types have been changed to allow for more modularity. This prepares the current structure for different output types (database) and more sensor devices
2025-01-03 Adapted Documentation
    Documentation should build correctly with material theme and inline documentation of CTD class
2025-01-04 Adapt stage paths
2025-01-04 Removed space from command in stage
2025-01-05 Fix install path and skip creation of stage2 image file
2025-01-05 Append to wpa_supplicant file instead of overwriting in case there is already content
2025-01-06 Enable I2C support to image
2025-02-05 Add Hotspot instead of connecting to mobile device
2025-02-06 Changed path management and fixed some smaller bugs
    [__main__.py, ctd.py]
2025-02-10 Run startable in web api. Installation of pyenv with correct python version
    [__main__.py, ctd.py]
2025-02-12 Return float value of depth as a measured value for the Bluerobotics depth sensor
2025-02-12 Add second sensor loop in order to minimize delay
2025-02-12 Fixed sleep and added usage documentation
    [ctd.py]
2025-02-13 Changed structure of the software. Added main thread loop. Added different run categories.
2025-02-13 Adapted logger color reset
    [logger.py]
2025-02-15 Switched database ORM to peewee
2025-11-01 Added i2c-tools to installed packages to simplify sensor debugging
